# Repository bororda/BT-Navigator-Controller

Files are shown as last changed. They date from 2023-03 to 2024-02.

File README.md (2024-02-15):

# Intro

This is a Bluetooth based smartphone/ tablet controller for the comfortable interactions with your navigation (not limited to but mainly for _OsmAnd_, _Locus Map_ and _Rally Roadbook Reader_ app) while riding your bike.

Current models are designed to be mounted over the grips, i.e. no manipulation with the handlebar setup is required other than just securing the controller on the left hand grip. Eventually the versions with other mounting diameters will appear.

The solution consists of 2 parts connected with the cable: hand grip module and the box with a dev board and batteries.

## Right now there're two versions of the grip module:
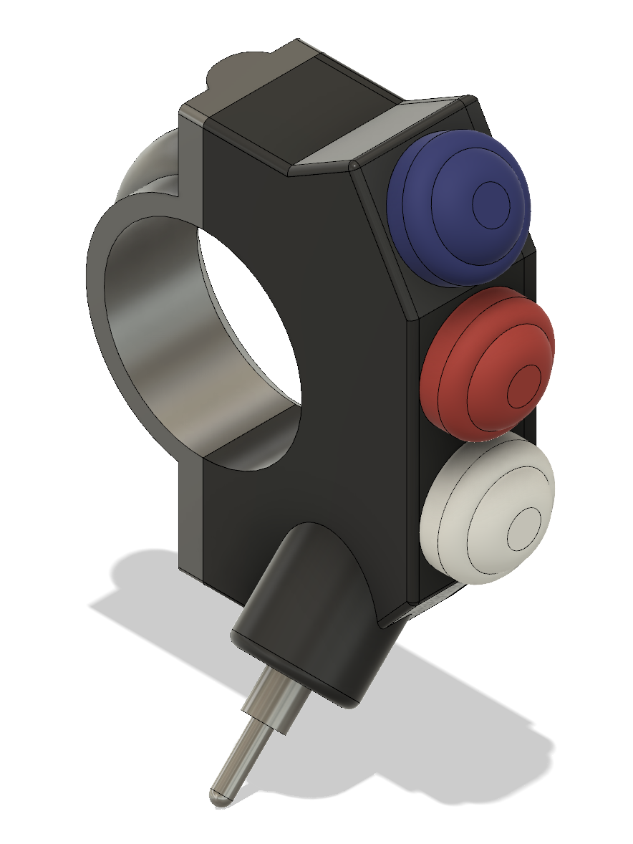
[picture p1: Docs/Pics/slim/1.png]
Slim Slim model
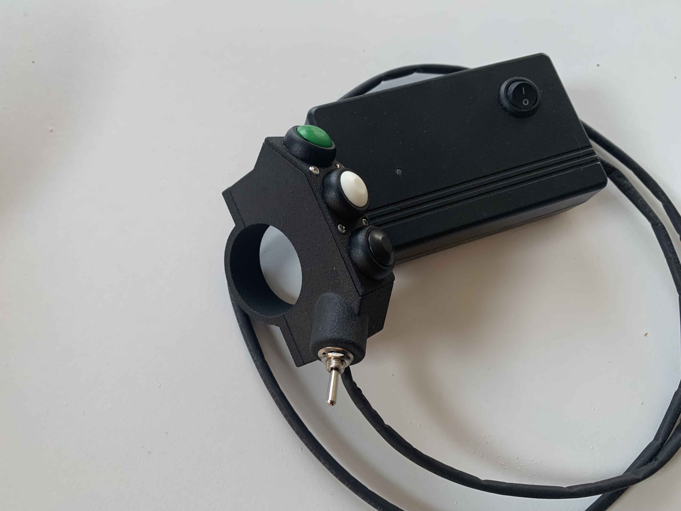
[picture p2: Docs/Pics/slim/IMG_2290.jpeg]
Slim Slim Assembled
1. **V2 aka Slim** redesigned controller. As rigit as V1, but signnificantly slimmer, with ergonomicly designed toggle switch position.   
2. **V1** which is quite wide and eats up a lot of grip space, plus it's looking rather basic - still functioning well. If printed out of nylon is rigit as hell. I personally would definitely go for the V2 Slim, but if you're curious you can still check the V1 here: [V1 3D](Docs/Pics/V1/1.png) and [V1 Assembled](Docs/Pics/V1/IMG_2272.jpeg)

The box with a dev board and batteries is basically somewhat of a water protected box to store the brains of the controller - check the [MAC Parts](Docs/parts.numbers) or [Excel Parts but w/o pics](Docs/parts.xlsx) for details.

# Instructions
## How to assemble one
1. Get the list of components listed in [MAC Parts](Docs/parts.numbers) or [Excel Parts but w/o pics](Docs/parts.xlsx)
2. Order the 3D prints. You gotta chose between the [V1](V1/Hardware/casing) and [V2 Slim](Slim/Hardware/case). Both are perfectly fine and durable, except the V2 is obviously slimmer and more compact compared to V1.
3. Flash the board. Both V1 and V2 Slim are based on ESP32 Wroom. You'll need the [BLE lib](Code/ESP32-BLE-Keyboard-master). Switching to [Seeed Studio XIAO nRF52840](https://wiki.seeedstudio.com/XIAO_BLE/)  is yet to come - this should improve the size of the external box.
4. Assemble the project. You'll need a soldering iron! Should you have any troubles on this step, give me a shout.
5. Turn the device on and connect it to your smartphone from Settings->Bluetooth
6. Configure the apps on the phone to react to the keys properly

## Buttons

### Buttons Defaults
From top to bottom the keys sent to the device are: letter "C", "Up Arrow", "Down Arrow". Toggle switch Vol+ when pressed towards, and Vol- when pulled.

### Navigation
Buttons cover the main functionality for the 2 navigation apps that are the most interesting for the author:
1. C to center the map
2. Vol+ and Vol- to zoom in and out
3. Up and Down Arrows for OsmAnd to move the map up and down

## Rally Roadbook Reader
Work in progress.
The solution is trivial: add a hardware switch and adjust the code to switch the key mapping. Unfortunately there's no common solution for both navigation and rally roadbook as some keys are different, but the common keys do different things. RRR does not let other keys to be assigned in the app, or the author was not clever enough to finnd the hidden settings.

## OsmAnd Setup
Follow the guide from the [official page](https://osmand.net/docs/user/map/interact-with-map/#external-input-device-buttons) to turn on the support of the External Input Devices. Also enable zoom in-out with volume buttons. If for any reason you would not want to do this last step, you would need to reconfigure the .ino sketch and adjust the code to send other keys.

# V1 vs. V2 Slim
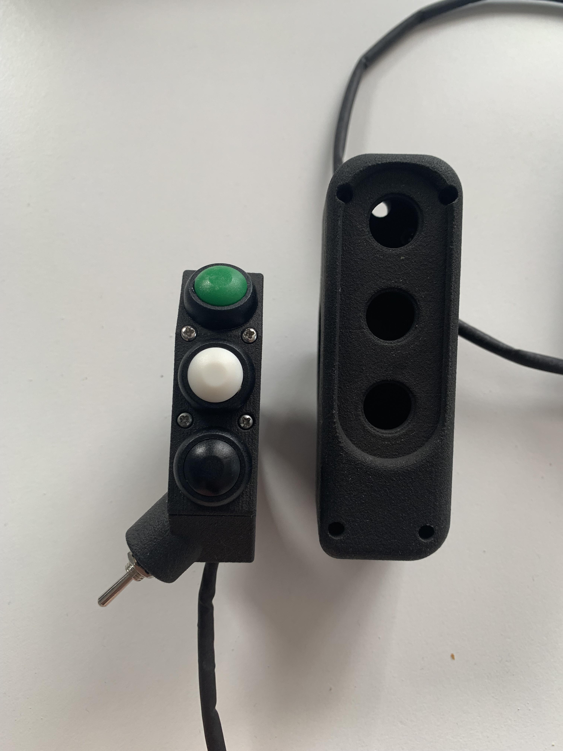
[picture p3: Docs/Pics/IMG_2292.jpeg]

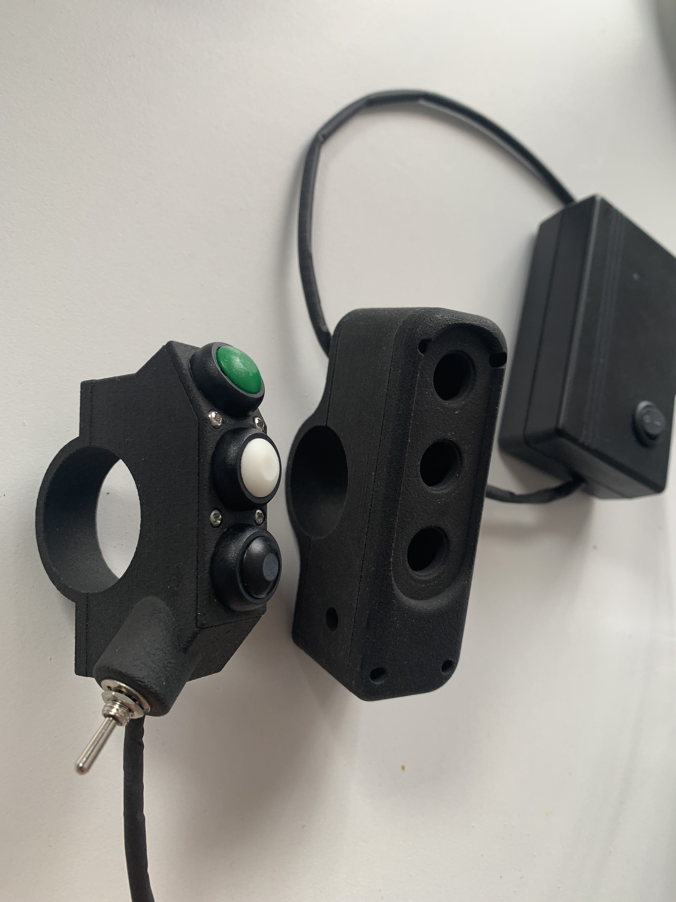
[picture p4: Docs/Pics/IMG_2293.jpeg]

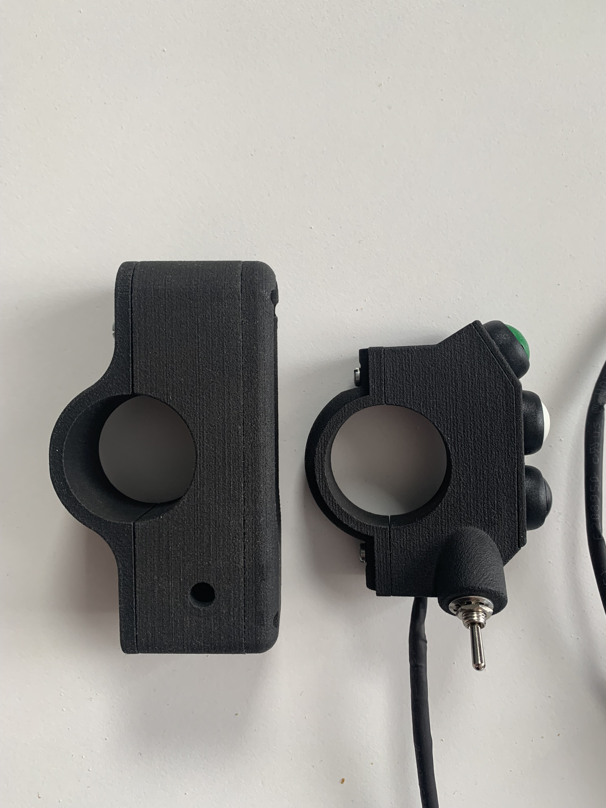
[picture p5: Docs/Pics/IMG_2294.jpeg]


# Credits
This project was inspired by another open source project [rallyrampage](https://www.rallyrampage.com/product/bluetooth-navigation-handlebar-controller-version-1-7-3-6b/)
You cannot reinvent something so simple, but i did put some efforts to make the controller look just a bit nicer and reduce the costs of the components.

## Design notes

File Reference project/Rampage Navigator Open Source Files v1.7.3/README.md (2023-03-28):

WELCOME TO THE RALLY RAMPAGE NAVIGATION CONTROLLER

This project is for developing a bluetooth handlebar controller to use for navigation whilst riding motorbike.

The project was started by Eugene Beetge from Rally Rampage. The original designs and coding are all from Eugene.

For more information please visit: 

https://www.rallyrampage.com

or 

email at info@rallyrampage.com

REVISIONS & RELEASES

Version 1.7.3 Release date 2022/03/31
-added default mode option to startup in an app
-added battery testing and display on mobile using keyboard text when in Mode select and pushing button 5 which is unassigned with an app. Used now for battery voltage testing and display push
-cleaned up code in other areas
-better notes inside code

Version 1.7.2  (Release date 2021/12/17)
- updated code for all 4 new apps
	Locus Maps
	Rally Navigator
	OsMand Maps
	Piste Roadbook

Version 1.7  (Release date 2021/12/14)
- complete new functionality using rocker switches.
- rocker one mode is to select one of 5 apps, with LED flicker to confirm app selected.
- rocker two mode is using the app selected.
- accomodating for normaly-open and normaly-closed controller buttons in code. Easy to select
- code half size, double the speed

Version 1.5  (Release date 2021/09/27)
- included 3d print files
- 2 versions of 3d print files with different designs to make manufacturing easier
- permanent power option in the design

Version 1.2 (Release date 2021/06/27)
- original open source files

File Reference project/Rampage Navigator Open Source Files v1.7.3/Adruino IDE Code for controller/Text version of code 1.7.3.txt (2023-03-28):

//VERSION 1.7.3
// This version allow for the selection of various apps by putting the unit in MODE as well as reading the battery status
// and then selecting the appropriate app based on the button pressed. Here are the apps and buttons
// WHEN YOU PLACE THE UNIT IN MODE SELECT AND THE LED IS RED, BY PRESSING THE FOLLOWING BUTTONS YOU CAN SELECT THE APP THE KEYS ARE ASSIGNED TO FOR WHEN YOU GO BACK TO RIDING MODE
// Button 1. Locus Maps
// Button 2. Rally Navigator
// Button 3. OsmAnd
// Button 4. Piste Roadbook Reader
// Button 5. Battery level check and sending back to Androidn device as text. Can be seen on any text interface
// Toggle 6 (Toggle switch). Locus Maps (as backup incase your buttons to select arent working or you are using something else)
// Toggle 7 (Toggle switch). Rally Navigator  (as backup incase your buttons to select arent working or you are using something else)

#include <Arduino.h>
#include <SPI.h>
#include "Adafruit_BLE.h"
#include "Adafruit_BluefruitLE_SPI.h"
#include "Adafruit_BluefruitLE_UART.h"

#if SOFTWARE_SERIAL_AVAILABLE
#include <SoftwareSerial.h>
#endif

Adafruit_BluefruitLE_SPI ble(8, 7, 4);

//Factory reset to 0 for no reset, or 1 to factory reset when scketch starts
#define FACTORYRESET_ENABLE 0

/////////////////////////////////////////////////////////
//Choose some setting that may be different on your unit
/////////////////////////////////////////////////////////

//APP LED SEQUENCE OF COLOUR. SWOP THE VALUE OF YOUR COLCOURS ARE WRONG WAY AROUND
const int ledGREEN = A1;
const int ledRED = A0;

//PUSH BUTTONS STATE FOR NORMALLY OPEN AND NORMALLY CLOSED
//FOR Normally open buttons keen the state LOW.
//FOR Normally closed buttons change the state to HIGH
const int button1state = LOW;
const int button2state = LOW;
const int button3state = LOW;
const int button4state = LOW;
const int button5state = LOW;
const int button6state = LOW;
const int button7state = LOW;

/////////////////////////////////////////////////////////

//PUSH BUTTONS
const int button1 = 12; //Black
const int button2 = 11; //Dark blue
const int button3 = 10; //Blue
const int button4 = 9; //White
const int button5 = 5; //Dark blue

//TOGGLE SWITCH BUTTONS
const int button6 = A2;
const int button7 = A3;

//APP SWITCH BUTTON
const int modeSelect = 6;
int softApp; //Keep softapp default 0 when starting up
//int softApp = 1; //preset softapp to app 3 when starting up

//BUTTON & TOGGLE FIXED SCROLL SPEED
const int buttonWait = 250;
const int toggleWait = 20;

////////////////////////////////////////////////////////////////////////////////////////////////
void setup()
{

  Serial.begin(115200);
  Serial.println("Starting up ...");

  /////////////////////////////////////////
  ////////SETUP BLUETOOTH
  /////////////////////////////////////////

  //Factory reset if enabled above
  if ( FACTORYRESET_ENABLE )
  {
    /* Perform a factory reset to make sure everything is in a known state */
    Serial.println(F("Performing a factory reset: "));
    if ( ! ble.factoryReset() ){
      //error(F("Couldn't factory reset"));
    }
  }

  //Setup BT
  ble.begin(false);
  ble.sendCommandCheckOK("AT+GAPDEVNAME=Rampage_Controller_1.7.3");
  ble.sendCommandCheckOK("AT+BLEHIDEN=On");
  ble.sendCommandCheckOK("AT+BleKeyboardEn=On");
  Serial.println("Bluetooth Started OK!");
  digitalWrite(LED_BUILTIN, LOW);

  //Double reset to see if it improves auto connect on Androidn devices
  ble.reset();
  delay(2000);
  ble.reset();

  /* Disable command echo from Bluefruit */
  ble.echo(false);

  /* Print Bluefruit information */
  Serial.println("Requesting Bluefruit info:");
  ble.info();

  //Push buttons
  pinMode(button1, INPUT_PULLUP);
  pinMode(button2, INPUT_PULLUP);
  pinMode(button3, INPUT_PULLUP);
  pinMode(button4, INPUT_PULLUP);
  pinMode(button5, INPUT_PULLUP);
  //Toggle switch buttons
  pinMode(button6, INPUT_PULLUP);
  pinMode(button7, INPUT_PULLUP);
  //Mode LEDs
  pinMode(ledGREEN, OUTPUT);
  pinMode(ledRED, OUTPUT);
  //App rocker switch
  pinMode(modeSelect, INPUT_PULLUP);

}

////////////////////////////////////////////////////////////////////////////////////////////////////////////////////////////////////////////////////////////////////////////////////////////////
void loop()
{

  //  Serial.print("SoftApp # at startup is: ");
  //  Serial.println(softApp);

  //////////////////////////////////////////////////////////////
  // START SOFT APP SELECT LOOP
  //////////////////////////////////////////////////////////////
  
  //Start of select softapp 1
  if (digitalRead(modeSelect) == LOW) {
    digitalWrite(ledRED, HIGH);
    digitalWrite(ledGREEN, LOW);
    if (digitalRead(button1) == button1state) {
      softApp = 1;
      Serial.println ("While in Mode Select you have selected softApp 1: Locus Maps.");
      ble.println("AT+BleKeyboard=SoftApp 1: Locus Maps. ");
      digitalWrite(ledRED, LOW);
      delay (500);
      for (int i = 1; i <= softApp; i++) {
        digitalWrite(ledGREEN, HIGH);
        delay(300);
        digitalWrite(ledGREEN, LOW);
        delay(300);
      }
      delay (300);
      digitalWrite(ledRED, HIGH);
    } 
    //End of select softapp 1

    //Start of select softapp 2
    if (digitalRead(button2) == button2state) {
      softApp = 2;
      Serial.println ("While in Mode Select you have selected softApp 2: Rally navigator.");
      ble.println("AT+BleKeyboard=SoftApp 2: Rally navigator. ");
      digitalWrite(ledRED, LOW);
      delay (500);
      for (int i = 1; i <= softApp; i++) {
        digitalWrite(ledGREEN, HIGH);
        delay(300);
        digitalWrite(ledGREEN, LOW);
        delay(300);
      }
      delay (300);
      digitalWrite(ledRED, HIGH);
    } 
    //End of select softapp 2

    //Start of select softapp 3
    if (digitalRead(button3) == button3state) {
      softApp = 3;
      Serial.println ("While in Mode Select you have selected softApp 3: OsMand.");
      ble.println("AT+BleKeyboard=SoftApp 3: OsMand. ");
      digitalWrite(ledRED, LOW);
      delay (500);
      for (int i = 1; i <= softApp; i++) {
        digitalWrite(ledGREEN, HIGH);
        delay(300);
        digitalWrite(ledGREEN, LOW);
        delay(300);
      }
      delay (300);
      digitalWrite(ledRED, HIGH);
    } 
    //End of select softapp 3

    //Start of select softapp 4
    if (digitalRead(button4) == button4state) {
      softApp = 4;
      Serial.println ("While in Mode Select you have selected softApp 4: Piste Roadbook Reader.");
      ble.println("AT+BleKeyboard=SoftApp 4: Piste Roadbook Reader. ");
      digitalWrite(ledRED, LOW);
      delay (500);
      for (int i = 1; i <= softApp; i++) {
        digitalWrite(ledGREEN, HIGH);
        delay(300);
        digitalWrite(ledGREEN, LOW);
        delay(300);
      }
      delay (300);
      digitalWrite(ledRED, HIGH);
    } 
    //End of select softapp 4

    //Start of select softapp 5
    if (digitalRead(button5) == button5state) {
      //softApp = 0;
      Serial.println ("While in Mode Select you have selected Button 5: VBat Voltage Check.");
      //ble.println("AT+BleKeyboard=Button 5: VBat Voltage Check. ");

      ////Read battery for UART sending unique to this button in mode
      #define VBATPIN A9 // Measuring battery first on pin A9
      pinMode(button4, LOW); //Button 4 assigned to A9 for voltage just set to LOW to give correct values
      float measuredvbat = analogRead(VBATPIN);
      measuredvbat *= 2;    // we divided by 2, so multiply back
      measuredvbat *= 3.3;  // Multiply by 3.3V, our reference voltage
      measuredvbat /= 1024; // convert to voltage
      if (measuredvbat <= 4) {
        Serial.print("Battery seems to be connected and voltage is: " );
        Serial.println(measuredvbat);
        //ble.print("AT+BleKeyboard=");
        //ble.println("Battery seems to be connected and charging. ");
        ble.print("AT+BleKeyboard= ");
        ble.print("PIN or battery voltage: ");
        ble.print(measuredvbat);
        ble.println("v. ");
      }
      else {
        Serial.print("Battery does NOT seem to be connected, PIN voltage is: " );
        Serial.println(measuredvbat);
        //ble.print("AT+BleKeyboard=");
        //ble.println("The battery does NOT seem to be connected. ");
        ble.print("AT+BleKeyboard= ");
        ble.print("PIN or battery voltage: ");
        ble.print(measuredvbat);
        ble.println("v. ");
      }
      pinMode(button4, INPUT_PULLUP); //Button 4 assigned to voltage pin 9 pulled up for deafult function again

      digitalWrite(ledRED, LOW);
      delay (500);
      for (int i = 1; i <= softApp; i++) {
        digitalWrite(ledGREEN, HIGH);
        delay(300);
        digitalWrite(ledGREEN, LOW);
        delay(300);
      }
      delay (300);
      digitalWrite(ledRED, HIGH);
    } 
    //End of select softapp 5

    //Start of select softapp 6
    if (digitalRead(button6) == button6state) {
      softApp = 1;
      Serial.println ("While in Mode Select you have selected softApp 1: Locus Maps button mapping.");
      ble.println("AT+BleKeyboard=SoftApp 1: Locus Maps. ");
      digitalWrite(ledRED, LOW);
      delay (500);
      for (int i = 1; i <= softApp; i++) {
        digitalWrite(ledGREEN, HIGH);
        delay(300);
        digitalWrite(ledGREEN, LOW);
        delay(300);
      }
      delay (300);
      digitalWrite(ledRED, HIGH);
    } 
    //End of select softapp 6

    //Start of select softapp 7
    if (digitalRead(button7) == button7state) {
      softApp = 2;
      Serial.println ("While in Mode Select you have selected softApp 2: Rally navigator.");
      ble.println("AT+BleKeyboard=SoftApp 2: Rally Navigator. ");
      digitalWrite(ledRED, LOW);
      delay (500);
      for (int i = 1; i <= softApp; i++) {
        digitalWrite(ledGREEN, HIGH);
        delay(300);
        digitalWrite(ledGREEN, LOW);
        delay(300);
      }
      delay (300);
      digitalWrite(ledRED, HIGH);
    } 
    //End of select softapp 7
    
  }

  //////////////////////////////////////////////////////////////
  // END SOFT APP SELECT LOOP
  //////////////////////////////////////////////////////////////

  //////////////////////////////////////////////////////////////
  // START SOFT APP RUN LOOP
  //////////////////////////////////////////////////////////////
  if (digitalRead(modeSelect) == HIGH) {
    digitalWrite(ledRED, LOW);
    digitalWrite(ledGREEN, HIGH);

    if (softApp == 0) { //App 0 No softApp value yet
      Serial.println("You are in softApp: ZERO");
      digitalWrite(ledGREEN, HIGH);
      delay(300);
      digitalWrite(ledGREEN, LOW);
      delay(300);
    } //End softapp 0

    if (softApp == 1) {  // App 1 Locus Maps
      digitalWrite(ledGREEN, HIGH);
      Serial.println("You are in softApp: Locus");
      //PUSH BUTTONS
      if (digitalRead(button1) == button1state) {
        Serial.println("Button 1");
        ble.sendCommandCheckOK("AT+BleHidControlKey=VOLUME+");
        digitalWrite(ledGREEN, LOW);
        delay(buttonWait);
        digitalWrite(ledGREEN, HIGH);
      }
      if (digitalRead(button2) == button2state) {
        Serial.println("Button 2");
        ble.sendCommandCheckOK("AT+BleHidControlKey=VOLUME-");
        digitalWrite(ledGREEN, LOW);
        delay(buttonWait);
        digitalWrite(ledGREEN, HIGH);
      }
      if (digitalRead(button3) == button3state) {
        Serial.println("Button 3");
        ble.sendCommandCheckOK("AT+BLEKEYBOARDCODE=00-00-15-00-00-00-00");
        ble.sendCommandCheckOK("AT+BLEKEYBOARDCODE=00-00");
        digitalWrite(ledGREEN, LOW);
        delay(buttonWait);
        digitalWrite(ledGREEN, HIGH);
      }
      if (digitalRead(button4) == button4state) {
        Serial.println("Button 4");
        ble.sendCommandCheckOK("AT+BLEKEYBOARDCODE=00-00-06-00-00-00-00");
        ble.sendCommandCheckOK("AT+BLEKEYBOARDCODE=00-00");
        digitalWrite(ledGREEN, LOW);
        delay(buttonWait);
        digitalWrite(ledGREEN, HIGH);
      }
      if (digitalRead(button5) == button5state) {
        Serial.println("Button 5");
        ble.sendCommandCheckOK("AT+BLEKEYBOARDCODE=00-00-07-00-00-00-00");
        ble.sendCommandCheckOK("AT+BLEKEYBOARDCODE=00-00");
        digitalWrite(ledGREEN, LOW);
        delay(buttonWait);
        digitalWrite(ledGREEN, HIGH);
      }
      //TOGGLE SWITCH
      if (digitalRead(button6) == button6state) {
        Serial.println("Button 6");
        ble.sendCommandCheckOK("AT+BleHidControlKey=VOLUME+");
        digitalWrite(ledGREEN, LOW);
        delay(buttonWait);
        digitalWrite(ledGREEN, HIGH);
      }
      if (digitalRead(button7) == button7state) {
        Serial.println("Button 7");
        ble.sendCommandCheckOK("AT+BleHidControlKey=VOLUME-");
        digitalWrite(ledGREEN, LOW);
        delay(buttonWait);
        digitalWrite(ledGREEN, HIGH);
      }
    } //End softapp 1

    if (softApp == 2) { // App 2 Rally Navigator
      digitalWrite(ledGREEN, HIGH);
      digitalWrite(ledRED, LOW);
      Serial.println("You are in softApp: Rally Navigator");
      //PUSH BUTTONS
      if (digitalRead(button1) == button1state) {
        Serial.println("Button 1");
        ble.sendCommandCheckOK("AT+BleHidControlKey=VOLUME+");
        digitalWrite(ledGREEN, LOW);
        delay(buttonWait);
        digitalWrite(ledGREEN, HIGH);
      }
      if (digitalRead(button2) == button2state) {
        Serial.println("Button 2");
        ble.sendCommandCheckOK("AT+BleHidControlKey=VOLUME-");
        digitalWrite(ledGREEN, LOW);
        delay(buttonWait);
        digitalWrite(ledGREEN, HIGH);
      }
      if (digitalRead(button3) == button3state) {
        Serial.println("Button 3");
        ble.sendCommandCheckOK("AT+BLEKEYBOARDCODE=00-00-15-00-00-00-00"); //Map Up or turn r
        ble.sendCommandCheckOK("AT+BLEKEYBOARDCODE=00-00");
        digitalWrite(ledGREEN, LOW);
        delay(buttonWait);
        digitalWrite(ledGREEN, HIGH);
      }
      if (digitalRead(button4) == button4state) {
        Serial.print("Button 4");
        ble.sendCommandCheckOK("AT+BleHidControlKey=MEDIANEXT");
        digitalWrite(ledGREEN, LOW);
        delay(buttonWait);
        digitalWrite(ledGREEN, HIGH);
      }
      if (digitalRead(button5) == button5state) {
        Serial.println("Button 5");
        ble.sendCommandCheckOK("AT+BleHidControlKey=MEDIAPREVIOUS");
        digitalWrite(ledGREEN, LOW);
        delay(buttonWait);
        digitalWrite(ledGREEN, HIGH);
      }
      //TOGGLE SWITCH
      if (digitalRead(button6) == button6state) {
        Serial.println("Button 6");
        ble.sendCommandCheckOK("AT+BleHidControlKey=MEDIANEXT");
        digitalWrite(ledGREEN, LOW);
        delay(buttonWait);
        digitalWrite(ledGREEN, HIGH);
      }
      if (digitalRead(button7) == button7state) {
        Serial.println("Button 7");
        ble.sendCommandCheckOK("AT+BleHidControlKey=MEDIAPREVIOUS");
        digitalWrite(ledGREEN, LOW);
        delay(buttonWait);
        digitalWrite(ledGREEN, HIGH);
      }
    } //End softapp 2

    if (softApp == 3) { // App 3 OsMand
      digitalWrite(ledGREEN, HIGH);
      digitalWrite(ledRED, LOW);
      Serial.println("You are in softApp: OsMand");
      //PUSH BUTTONS
      if (digitalRead(button1) == button1state) {
        Serial.println("Button1");
        ble.sendCommandCheckOK("AT+BLEKEYBOARDCODE=00-00-52-00-00-00-00");
        ble.sendCommandCheckOK("AT+BLEKEYBOARDCODE=00-00");
        digitalWrite(ledGREEN, LOW);
        delay(buttonWait);
        digitalWrite(ledGREEN, HIGH);
      }
      if (digitalRead(button2) == button2state) {
        Serial.println("Button2");
        ble.sendCommandCheckOK("AT+BLEKEYBOARDCODE=00-00-51-00-00-00-00");
        ble.sendCommandCheckOK("AT+BLEKEYBOARDCODE=00-00");
        digitalWrite(ledGREEN, LOW);
        delay(buttonWait);
        digitalWrite(ledGREEN, HIGH);
      }
      if (digitalRead(button3) == button3state) {
        Serial.println("Button3");
        ble.sendCommandCheckOK("AT+BLEKEYBOARDCODE=00-00-06-00-00-00-00");
        ble.sendCommandCheckOK("AT+BLEKEYBOARDCODE=00-00");
        digitalWrite(ledGREEN, LOW);
        delay(buttonWait);
        digitalWrite(ledGREEN, HIGH);
      }
      if (digitalRead(button4) == button4state) {
        Serial.println("Button4");
        ble.sendCommandCheckOK("AT+BLEKEYBOARDCODE=00-00-50-00-00-00-00");
        ble.sendCommandCheckOK("AT+BLEKEYBOARDCODE=00-00");
        digitalWrite(ledGREEN, LOW);
        delay(buttonWait);
        digitalWrite(ledGREEN, HIGH);
      }
      if (digitalRead(button5) == button5state) {
        Serial.println("Button5");
        ble.sendCommandCheckOK("AT+BLEKEYBOARDCODE=00-00-4F-00-00-00-00");
        ble.sendCommandCheckOK("AT+BLEKEYBOARDCODE=00-00");
        digitalWrite(ledGREEN, LOW);
        delay(buttonWait);
        digitalWrite(ledGREEN, HIGH);
      }
      //TOGGLE SWITCHES
      if (digitalRead(button6) == button6state) {
        Serial.println("Button6");
        ble.sendCommandCheckOK("AT+BLEKEYBOARDCODE=00-00-2E-00-00-00-00");
        ble.sendCommandCheckOK("AT+BLEKEYBOARDCODE=00-00");
        digitalWrite(ledGREEN, LOW);
        delay(buttonWait);
        digitalWrite(ledGREEN, HIGH);
      }
      if (digitalRead(button7) == button7state) {
        Serial.println("Button7");
        ble.sendCommandCheckOK("AT+BLEKEYBOARDCODE=00-00-2D-00-00-00-00");
        ble.sendCommandCheckOK("AT+BLEKEYBOARDCODE=00-00");
        digitalWrite(ledGREEN, LOW);
        delay(buttonWait);
        digitalWrite(ledGREEN, HIGH);
      }
    } //End softapp 3

    if (softApp == 4) { // App 4 Piste
      digitalWrite(ledGREEN, HIGH);
      digitalWrite(ledRED, LOW);
      Serial.println("You are in softApp: Piste");
      //PUSH BUTTONS
      if (digitalRead(button1) == button1state) {
        Serial.println("Button 1");
        ble.sendCommandCheckOK("AT+BLEKEYBOARDCODE=00-00-1A-00-00-00-00"); //0x1A Keyboard w and W
        ble.sendCommandCheckOK("AT+BLEKEYBOARDCODE=00-00");
        digitalWrite(ledGREEN, LOW);
        delay(buttonWait);
        digitalWrite(ledGREEN, HIGH);
      }
      if (digitalRead(button2) == button2state) {
        Serial.println("Button 2");
        ble.sendCommandCheckOK("AT+BLEKEYBOARDCODE=00-00-1B-00-00-00-00"); //0x1B Keyboard x and X
        ble.sendCommandCheckOK("AT+BLEKEYBOARDCODE=00-00");
        digitalWrite(ledGREEN, LOW);
        delay(buttonWait);
        digitalWrite(ledGREEN, HIGH);
      }
      if (digitalRead(button3) == button3state) {
        Serial.println("Button 3");
        ble.sendCommandCheckOK("AT+BLEKEYBOARDCODE=00-00-04-00-00-00-00"); //0x04 Keyboard a and A
        ble.sendCommandCheckOK("AT+BLEKEYBOARDCODE=00-00");
        digitalWrite(ledGREEN, LOW);
        delay(buttonWait);
        digitalWrite(ledGREEN, HIGH);
      }
      if (digitalRead(button4) == button4state) {
        Serial.println("Button 4");
        ble.sendCommandCheckOK("AT+BLEKEYBOARDCODE=00-00-07-00-00-00-00"); //0x07 Keyboard d and D
        ble.sendCommandCheckOK("AT+BLEKEYBOARDCODE=00-00");
        digitalWrite(ledGREEN, LOW);
        delay(buttonWait);
        digitalWrite(ledGREEN, HIGH);
      }
      if (digitalRead(button5) == button5state) {
        Serial.println("Button 5");
        ble.sendCommandCheckOK("AT+BLEKEYBOARDCODE=00-00-14-00-00-00-00"); //0x14 Keyboard q and Q
        ble.sendCommandCheckOK("AT+BLEKEYBOARDCODE=00-00");
        digitalWrite(ledGREEN, LOW);
        delay(buttonWait);
        digitalWrite(ledGREEN, HIGH);
      }
      //TOGGLE SWITCH
      if (digitalRead(button6) == button6state) {
        Serial.println("Button 6");
        ble.sendCommandCheckOK("AT+BLEKEYBOARDCODE=00-00-14-00-00-00-00"); //0x07 Keyboard d and D
        ble.sendCommandCheckOK("AT+BLEKEYBOARDCODE=00-00");
        digitalWrite(ledGREEN, LOW);
        delay(buttonWait);
        digitalWrite(ledGREEN, HIGH);
      }
      if (digitalRead(button7) == button7state) {
        Serial.println("Button 7");
        ble.sendCommandCheckOK("AT+BLEKEYBOARDCODE=00-00-7-00-00-00-00"); //0x14 Keyboard q and Q
        ble.sendCommandCheckOK("AT+BLEKEYBOARDCODE=00-00");
        digitalWrite(ledGREEN, LOW);
        delay(buttonWait);
        digitalWrite(ledGREEN, HIGH);
      }
    } //End softapp 4

  } //End of HIGH state button loo

} //End of code

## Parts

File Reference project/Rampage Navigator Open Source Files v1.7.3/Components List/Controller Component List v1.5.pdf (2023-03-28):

# What do you need to build this unit?

You will need to do and get the following:
- some electronic components to build your bluetooth board with buttons.
- A 3D printer to print the controller and housing.
- Soldering and electronic assembly with wires.
- Upload code onto your board using the Arduino IDE.
- Common sense…lol.. No seriously, you will need to think practically.

# Components List

For this project you will need the following components:

© Rally Rampage 2021 - www.rallyrampage.com | Page 3 of 15
Made available under GNU Affero General Public License v3.0
# | Component | Qty | Online link of product and example

1 | Adafruit 32u4 Bluefruit Board | 1 | https://www.robotics.org.za/AF2829
2 | Mini Switch 12mm Waterproof | 6 | https://www.robotics.org.za/PBS-33B
3 | Rocker Switch | 2 | https://www.robotics.org.za/KCD11
4 | Toggle switch - center return | 1 | https://www.communica.co.za/products/m2019ss1w 01 (https://www.communica.co.za/products/m2019ss1w01)
5 | UTP Cable | 1 | Any 8 core UTP cable to use between your switches and your bluetooth box
6 | Wires | 1 | Additional wire to connect between switches and common joints
7 | 2 Colour LED | 1 | https://www.robotics.org.za/RG5-10
8 | M2 Screws | 10 | Miniature screws to attached lids
9 | 1000mA battery (FOR OPTION 1 DESIGN) | 1 | https://www.robotics.org.za/DTP603450?search=100 0ma (https://www.robotics.org.za/DTP603450?search=1000ma) Battery to use for power if not permanently powered
10 | 5v Step down regulator (For OPTION 2 design) | 1 | https://www.robotics.org.za/3792 Used for permanent power on your unit to use your vehicle's 12v perm source.
11 | Micro USB Charging Cable (For OPTION 2 design) | 1 | To be used for the regulator and cut up for perm power OPTION 2

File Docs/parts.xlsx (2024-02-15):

Slim
Part | id | Link | Qty | Ref Pic | Price
Toggle | MTS-123(ON)-OFF-(ON) | https://pl.aliexpress.com/item/1005001709262331.html?curPageLogUid=GSNrjsSGEd9Y&utparam-url=scene:search|query_from: | 1 |  | PLN 13
Push button |  | https://pl.aliexpress.com/item/1005004066257419.html | 3 |  | PLN 10
Main board w/ BLE one to choose | Seeed Xiao BLE nRF52840 | https://botland.com.pl/plytki-zgodne-z-arduino-pozostale/21259-seeed-xiao-ble-nrf52840-arduino-micropython-bluetooth-50-z-wbudowana-antena-seeedstudio-1020104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 | 1 |  | PLN 80
 | ESP-WROOM-32 ESP-32 WiFi Bluetooth MicroUSB | https://botland.com.pl/moduly-wifi-i-bt-esp32/8893-esp32-wifi-bt-42-platforma-z-modulem-esp-wroom-32-zgodny-z-esp32-devkit-5904422337438.html | 1 |  | PLN 65
Rocker switch | Power switch to turn off the power from the board | https://pl.aliexpress.com/item/1005005944839290.html?curPageLogUid=hMoaKqBciwiI&utparam-url=scene:search|query_from: | 1 |  | PLN 10
Battery | Vape battery | Żabka | 1 |  | PLN 20
Casing 3D print | JLC PCB | Use Nylon for durability |  |  | EUR 20
Cable | Any USB cable will work |  | <1m
Case for board & battery |  | https://pl.aliexpress.com/item/1005005467281776.html?curPageLogUid=wZyLFUqxeSAb&utparam-url=scene:search|query_from: | 1 |  | PLN 10
BMS | FDC-2S-2 | Depending on the powering setup you might need to consider a balancer for the double battery setup and a step-down DCDC converter | 1
Total |  |  |  |  | PLN 250

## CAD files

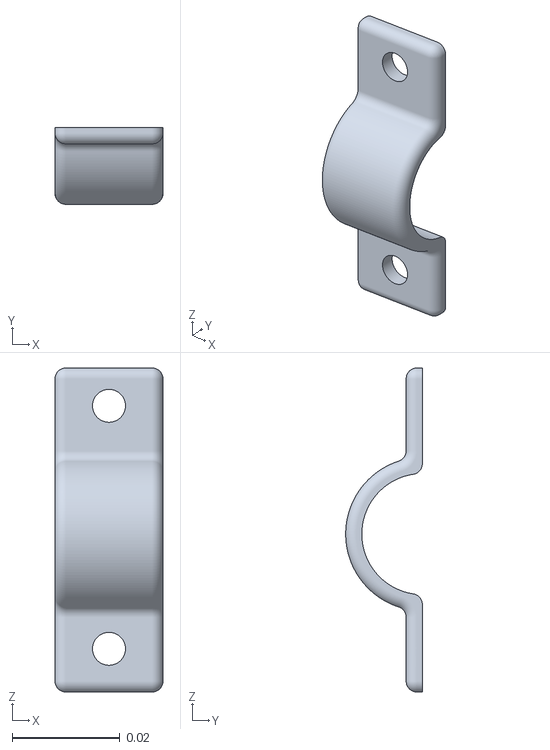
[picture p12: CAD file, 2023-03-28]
Reference project/Rampage Navigator Open Source Files v1.7.3/3D Print files/Bluetooth Controller v1.3 ORIGINAL SOLID DESIGN/STL Files/Controller buttons 1.2.1 Solid one side - Back plate.stl
0.02 x 0.0142 x 0.06

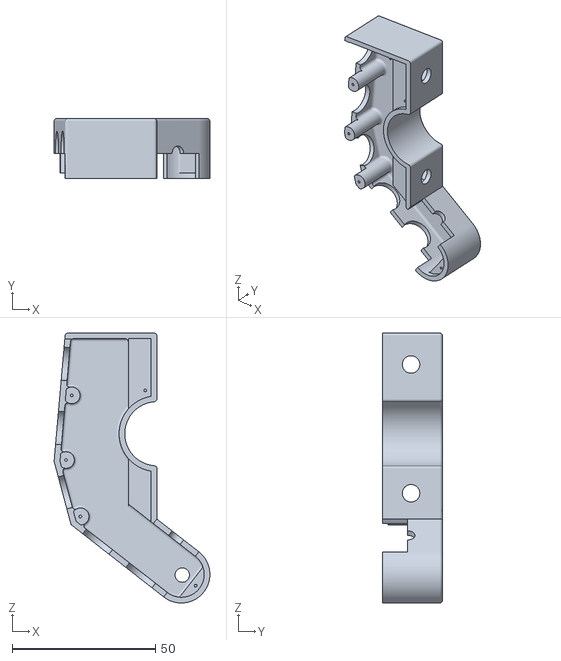
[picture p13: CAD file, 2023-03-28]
Reference project/Rampage Navigator Open Source Files v1.7.3/3D Print files/Bluetooth Controller v1.5 TWO SIDED OPTION FOR EASIER SOLDERING/STL Files/Controller button 1.5 - Body.stl
54.5 x 21.0 x 94.3

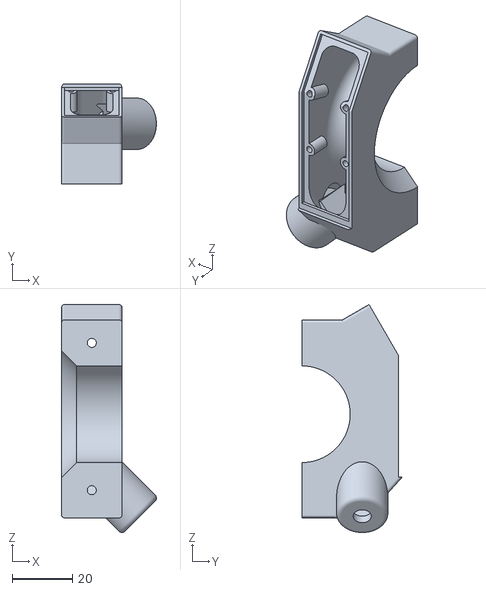
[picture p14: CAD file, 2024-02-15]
Slim/Hardware/case/Body1.stl
31.4 x 33.2 x 75.5

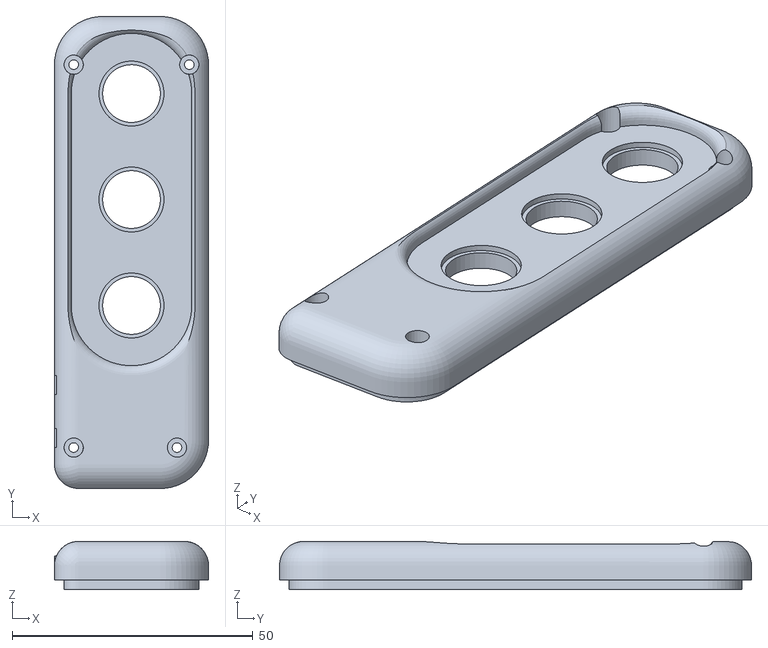
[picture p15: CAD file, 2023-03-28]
V1/Hardware/casing/Untitled3 v1.stl
32.0 x 98.0 x 10.0

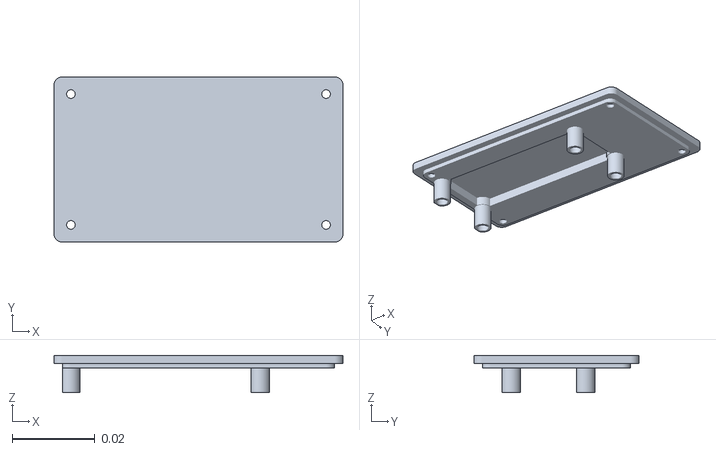
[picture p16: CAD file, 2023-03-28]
Reference project/Rampage Navigator Open Source Files v1.7.3/3D Print files/Bluetooth Controller v1.3 ORIGINAL SOLID DESIGN/STL Files/Bluetooth box 1.1 - Lid.stl
0.07 x 0.04 x 0.009

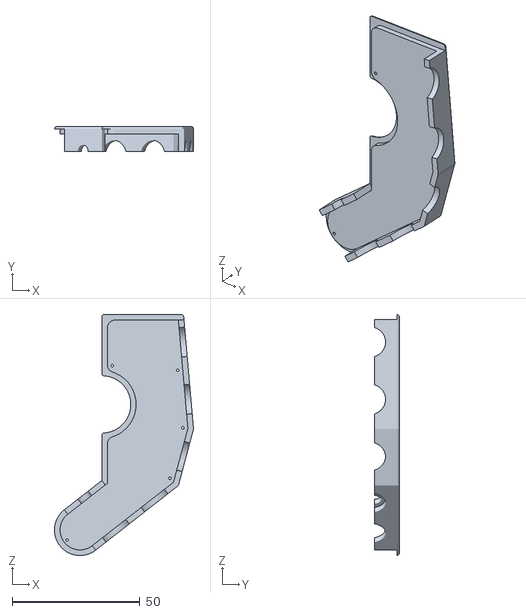
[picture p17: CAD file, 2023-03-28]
Reference project/Rampage Navigator Open Source Files v1.7.3/3D Print files/Bluetooth Controller v1.5 TWO SIDED OPTION FOR EASIER SOLDERING/STL Files/Controller button 1.5 - Lid.stl
54.5 x 9.78 x 94.3

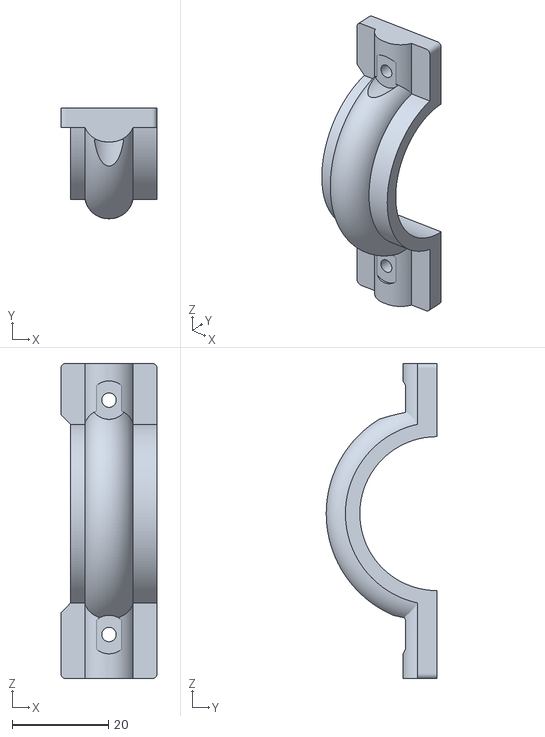
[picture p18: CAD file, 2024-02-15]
Slim/Hardware/case/Body11.stl
20.0 x 23.0 x 65.5

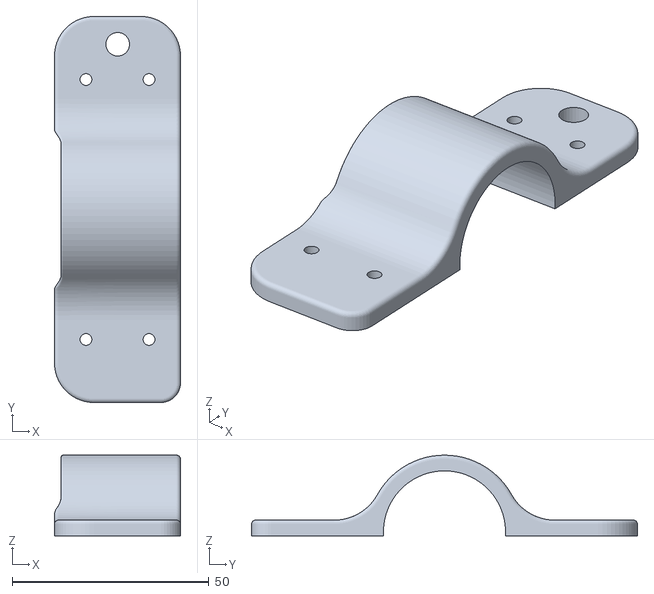
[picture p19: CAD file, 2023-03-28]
V1/Hardware/casing/Untitled2 v1.stl
32.0 x 98.0 x 20.5

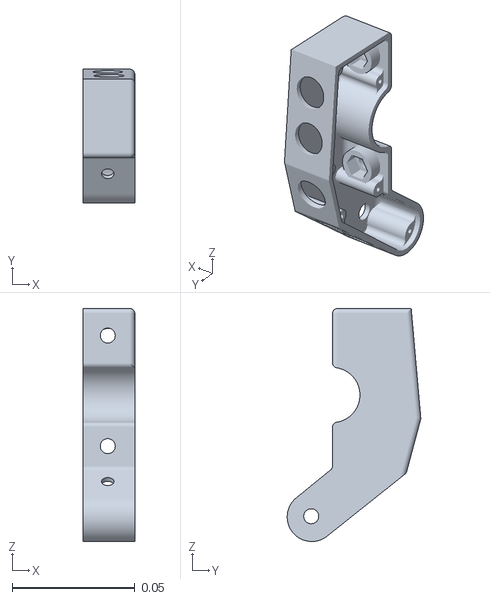
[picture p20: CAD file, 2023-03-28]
Reference project/Rampage Navigator Open Source Files v1.7.3/3D Print files/Bluetooth Controller v1.3 ORIGINAL SOLID DESIGN/STL Files/Controller buttons 1.2.1 Solid one side - Casing.stl
0.021 x 0.0544 x 0.0948

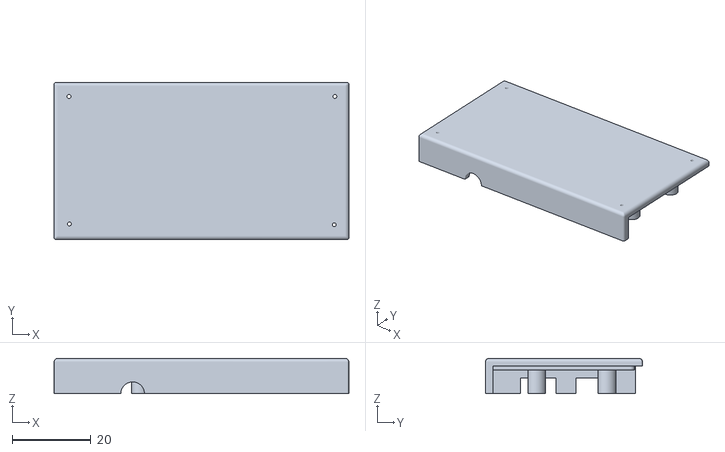
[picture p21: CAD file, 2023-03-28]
Reference project/Rampage Navigator Open Source Files v1.7.3/3D Print files/Bluetooth Controller v1.5 TWO SIDED OPTION FOR EASIER SOLDERING/STL Files/Bluetooth box 1.5 - Lid.stl
75.0 x 40.0 x 9.00

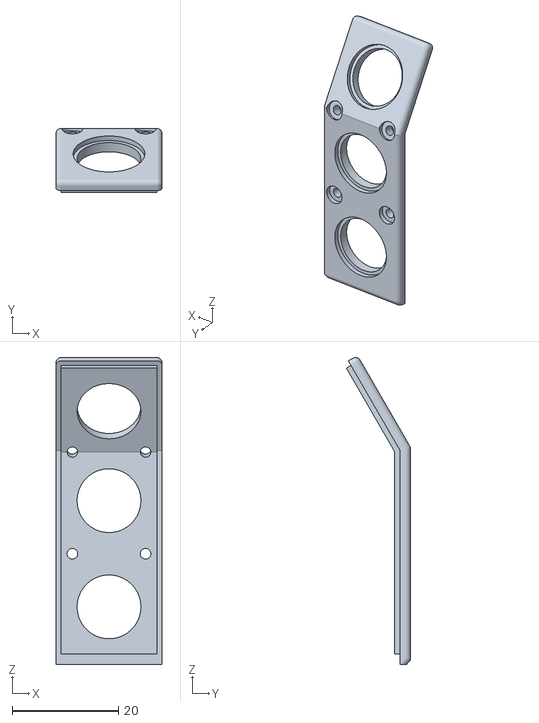
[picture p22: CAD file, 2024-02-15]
Slim/Hardware/case/Body7.stl
20.0 x 12.1 x 57.8

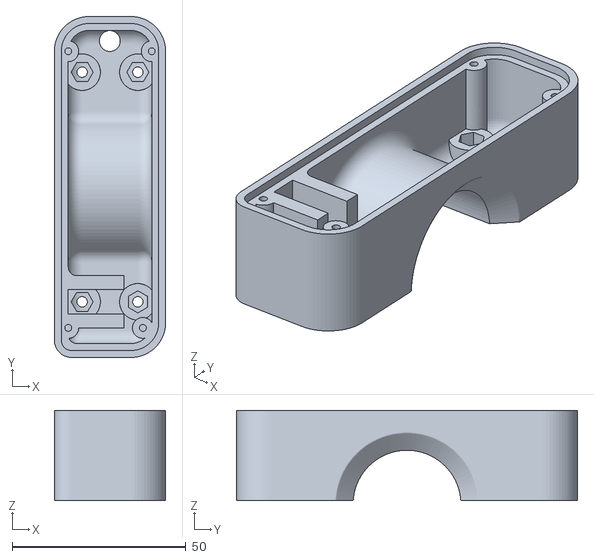
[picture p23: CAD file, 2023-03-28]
V1/Hardware/casing/Untitled v7.stl
32.0 x 98.0 x 26.0

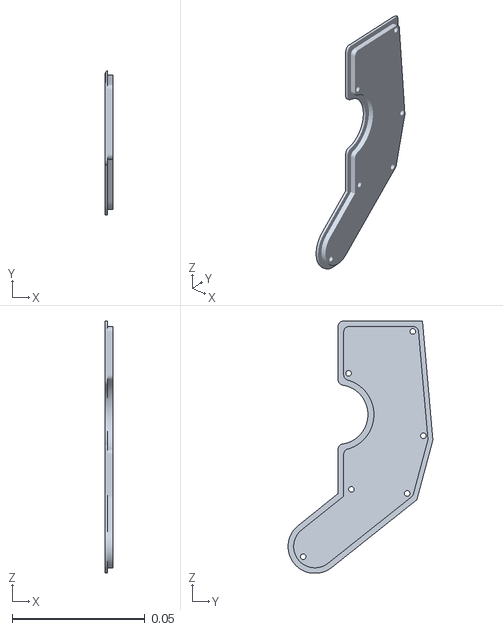
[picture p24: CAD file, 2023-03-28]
Reference project/Rampage Navigator Open Source Files v1.7.3/3D Print files/Bluetooth Controller v1.3 ORIGINAL SOLID DESIGN/STL Files/Controller buttons 1.2.1 Solid one side - lid.stl
0.003 x 0.0545 x 0.0948

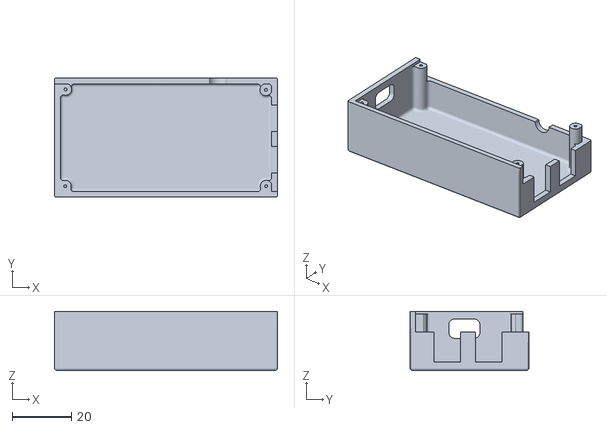
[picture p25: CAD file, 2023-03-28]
Reference project/Rampage Navigator Open Source Files v1.7.3/3D Print files/Bluetooth Controller v1.5 TWO SIDED OPTION FOR EASIER SOLDERING/STL Files/Bluetooth box 1.5 - Box.stl
75.0 x 40.0 x 20.0

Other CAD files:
Reference project/Rampage Navigator Open Source Files v1.7.3/3D Print files/Bluetooth Controller v1.3 ORIGINAL SOLID DESIGN/STL Files/Bluetooth box 1.1 - Box.stl
Reference project/Rampage Navigator Open Source Files v1.7.3/3D Print files/Bluetooth Controller v1.5 TWO SIDED OPTION FOR EASIER SOLDERING/STL Files/Controller button 1.5 - Back.stl
V1/Hardware/casing/Untitled v8.f3d
V1/Hardware/casing/Untitled2 v1.f3d
V1/Hardware/casing/Untitled3 v1.f3d

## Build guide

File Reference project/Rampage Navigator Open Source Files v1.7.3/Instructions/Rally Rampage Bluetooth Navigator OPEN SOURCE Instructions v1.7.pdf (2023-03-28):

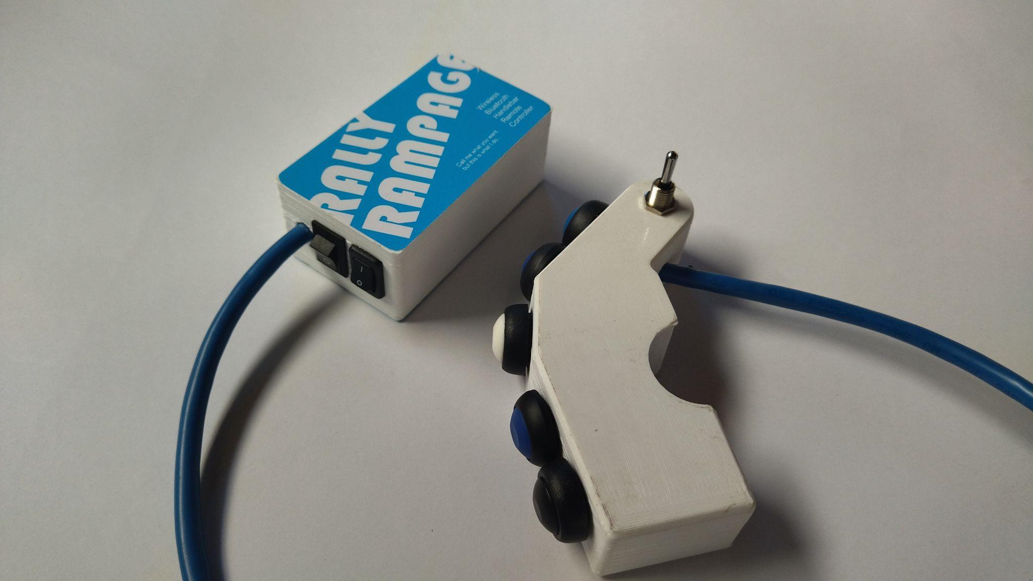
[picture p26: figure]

# Welcome to our

# Rampage Navigator

# Project!

Version 1.7
Updated: 20211214

This document is the explanation and instructions to assemble your own device. In the design and making of the unit, we have kept in mind the use of over-the-counter products. This will play a role in helping you source any exact components or similar components for your project.

What's included in these instructions:
- Components list
- 3D print model files
- Stickers for your little unit
- Some instructions on assembly
- Arduino IDE code for your Adafruit 32u4 board

# So let's get started!

© Rally Rampage 2021 - www.rallyrampage.com | Page 1 of 18
Made available under GNU Affero General Public License v3.0

So let's get started! | 1
What do you need to build this unit? | 3
Components List | 3
Tools | 4
Adafruit Board Default Layout | 5
The Rampage Nav Circuit Design | 6
Notes on circuit assembly | 7
Instructions | 8
Arduino IDE Sketch Explanation | 10
Final testing | 11
Suggestions | 11
Final thoughts | 12
Open Source License - Conditions | 13
GITHUB | 13
© Rally Rampage 2021 - www.rallyrampage.com | Page 2 of 18

## What do you need to build this unit?

You will need to do and get the following:
- some electronic components to build your bluetooth board with buttons.
- A 3D printer to print the controller and housing.
- Soldering and electronic assembly with wires.
- Upload code onto your board using the Arduino IDE.
- Common sense…lol.. No seriously, you will need to think practically.

## Components List

For this project you will need the following components:

# | Component | Qty | Online link of product and example

1 | Adafruit 32u4 Bluefruit Board | 1 | https://www.robotics.org.za/AF2829
2 | Mini Switch 12mm Waterproof | 6 | https://www.robotics.org.za/PBS-33B
3 | Rocker Switch | 2 | https://www.robotics.org.za/KCD11
4 | Toggle switch - center return | 1 | https://www.communica.co.za/products/m2019ss1w0 1 (https://www.communica.co.za/products/m2019ss1w01)
5 | UTP Cable | 1 | Any 8 core UTP cable to use between your switches and your bluetooth box
6 | Wires | 1 | Additional wire to connect between switches and common joints
7 | 2 Colour LED | 1 | https://www.robotics.org.za/RG5-10
8 | M2 Screws | 10 | Miniature screws to attached lids
9 | 1000mA battery (FOR OPTION 1 DESIGN) | 1 | https://www.robotics.org.za/DTP603450?search=100 0ma (https://www.robotics.org.za/DTP603450?search=1000ma) Battery to use for power if not permanently powered
10 | 5v Step down regulator (For OPTION 2 design) | 1 | https://www.robotics.org.za/3792 Used for permanent power on your unit to use your vehicle's 12v perm source.
11 | Micro USB Charging Cable (For OPTION 2 design) | 1 | To be used for the regulator and cut up for perm power OPTION 2
© Rally Rampage 2021 - www.rallyrampage.com | Page 3 of 18

## Tools

You will need the following minimum tools to build this device:
- Soldering iron and solder
- Wire cutters
- Wire stripper
- Computer with Arduino IDE installed
© Rally Rampage 2021 - www.rallyrampage.com | Page 4 of 18

## Adafruit Board Default Layout

The default PIN layout for this Adafruit board is as follows:

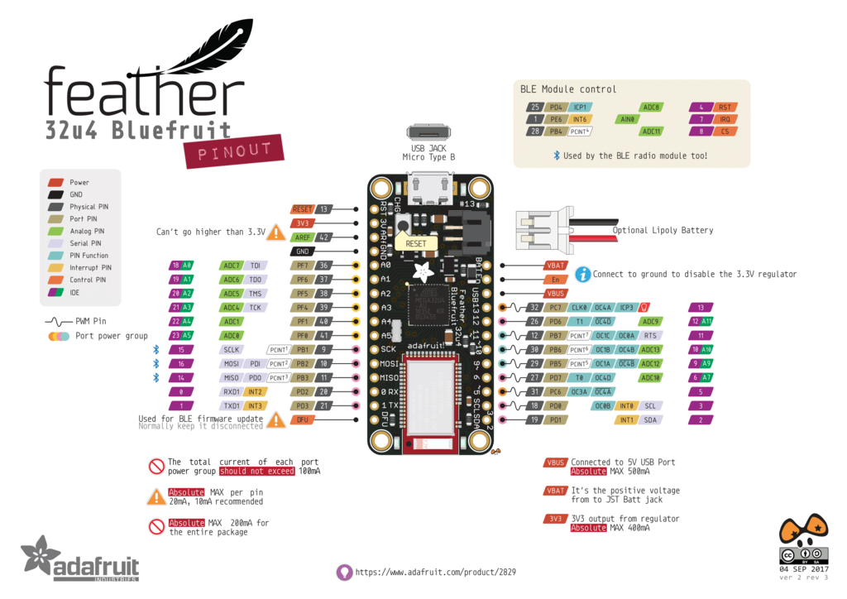
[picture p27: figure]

For more information about this board and how to set it up click this link: https://learn.adafruit.com/adafruit-feather-32u4-bluefruit-le?view=all

© Rally Rampage 2021 - www.rallyrampage.com | Page 5 of 18

## DESIGNS OPTION1: The Rampage Nav Circuit Design with Li Battery

The circuit design and buttons we are using are the following:

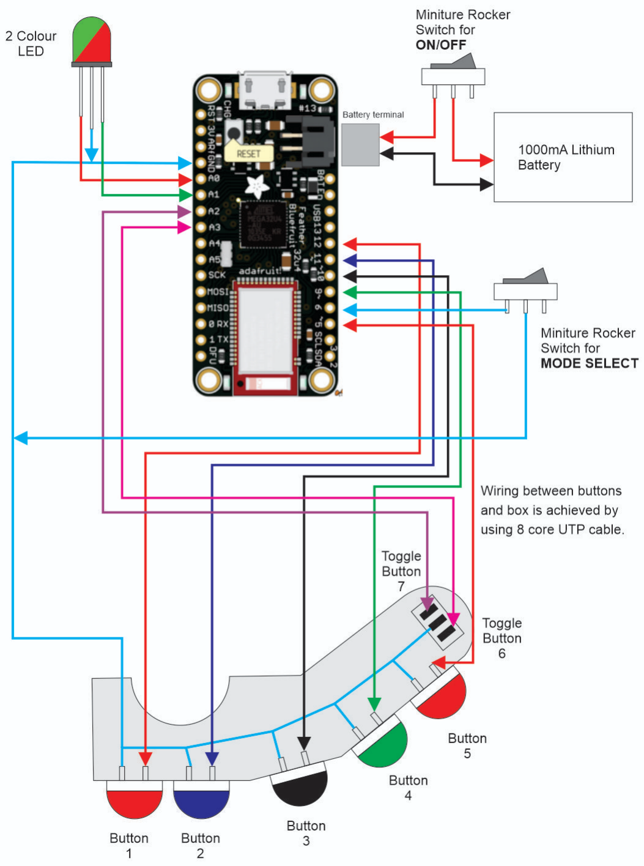
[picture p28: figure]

© Rally Rampage 2021 - www.rallyrampage.com | Page 6 of 18

### Notes on circuit assembly for Option 1

- The ground (GND) will need to go to all the buttons, one rocker switch and the central LED PIN.
- The LED PINs are close enough to just bend and solder directly into the board.
- The main mode LED must stick through the larger hole in the box.
- The battery lies at the bottom of the bluetooth box.
- Wiring between buttons and box is achieved by using 8 core UTP cable.
© Rally Rampage 2021 - www.rallyrampage.com | Page 7 of 18

## DESIGNS OPTION 2: The Rampage Nav Circuit Design with permanent power from 12v vehicle

The circuit design and buttons we are using are the following:

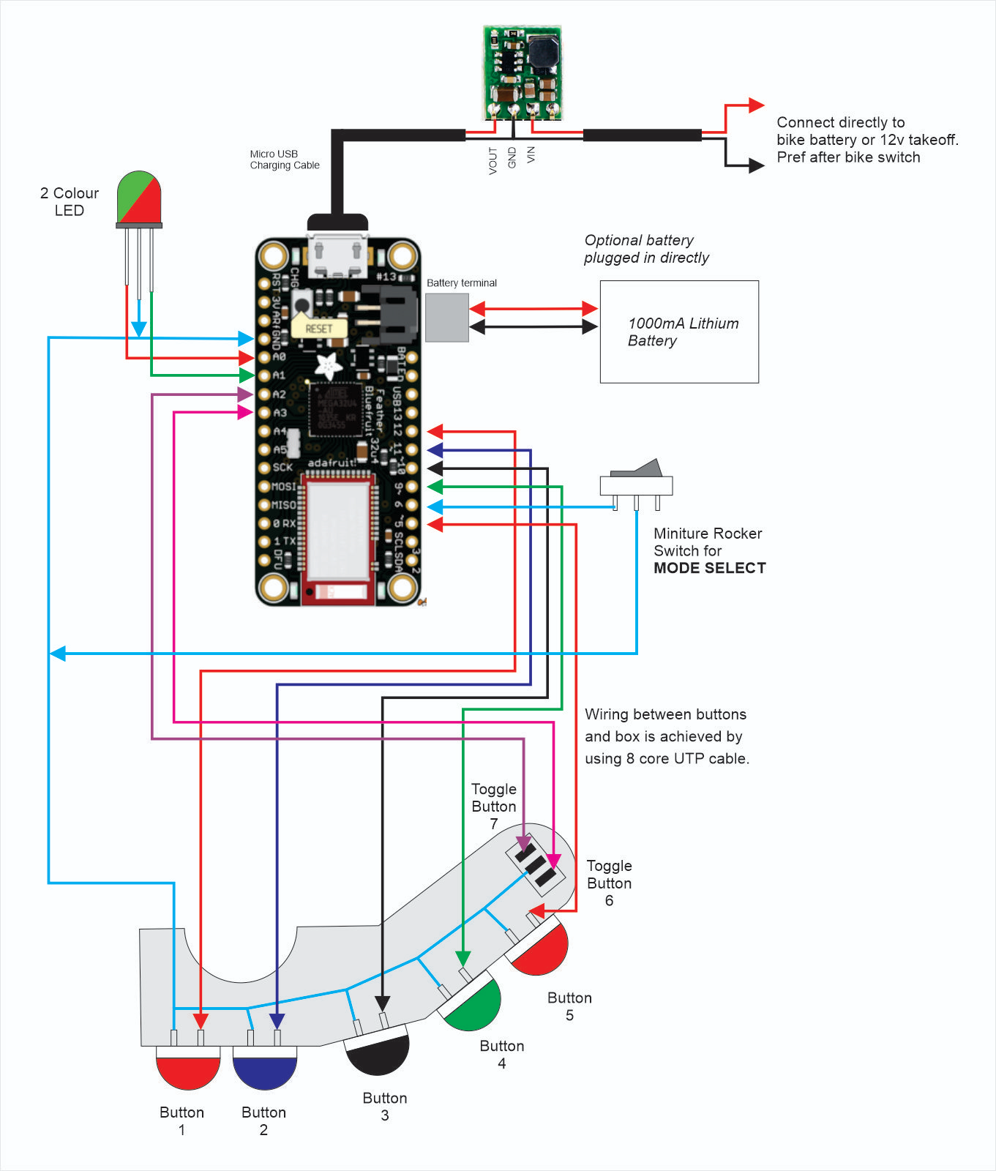
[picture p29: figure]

© Rally Rampage 2021 - www.rallyrampage.com | Page 8 of 18

### Notes on circuit assembly for Option 2:

- The ground (GND) will need to go to all the buttons, one rocker switch and the central LED PIN.
- The LED PINs are close enough to just bend and solder directly into the board.
- The main mode LED must stick through the larger hole in the box.
- The battery lies at the bottom of the bluetooth box.
- Wiring between buttons and box is achieved by using 8 core UTP cable.
- For the perm power use an existing USB charging cable and simply solder the 5v regulator in the middle of the cable. Use the micro USB in your unit and cut off the larger USB as you will need positive and negative directly.
© Rally Rampage 2021 - www.rallyrampage.com | Page 9 of 18

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
v3.0

## DESIGNS OPTION 3: The Rampage Nav Circuit Design with permanent power from 12v vehicle & battery backup

The circuit design and buttons we are using are the following:

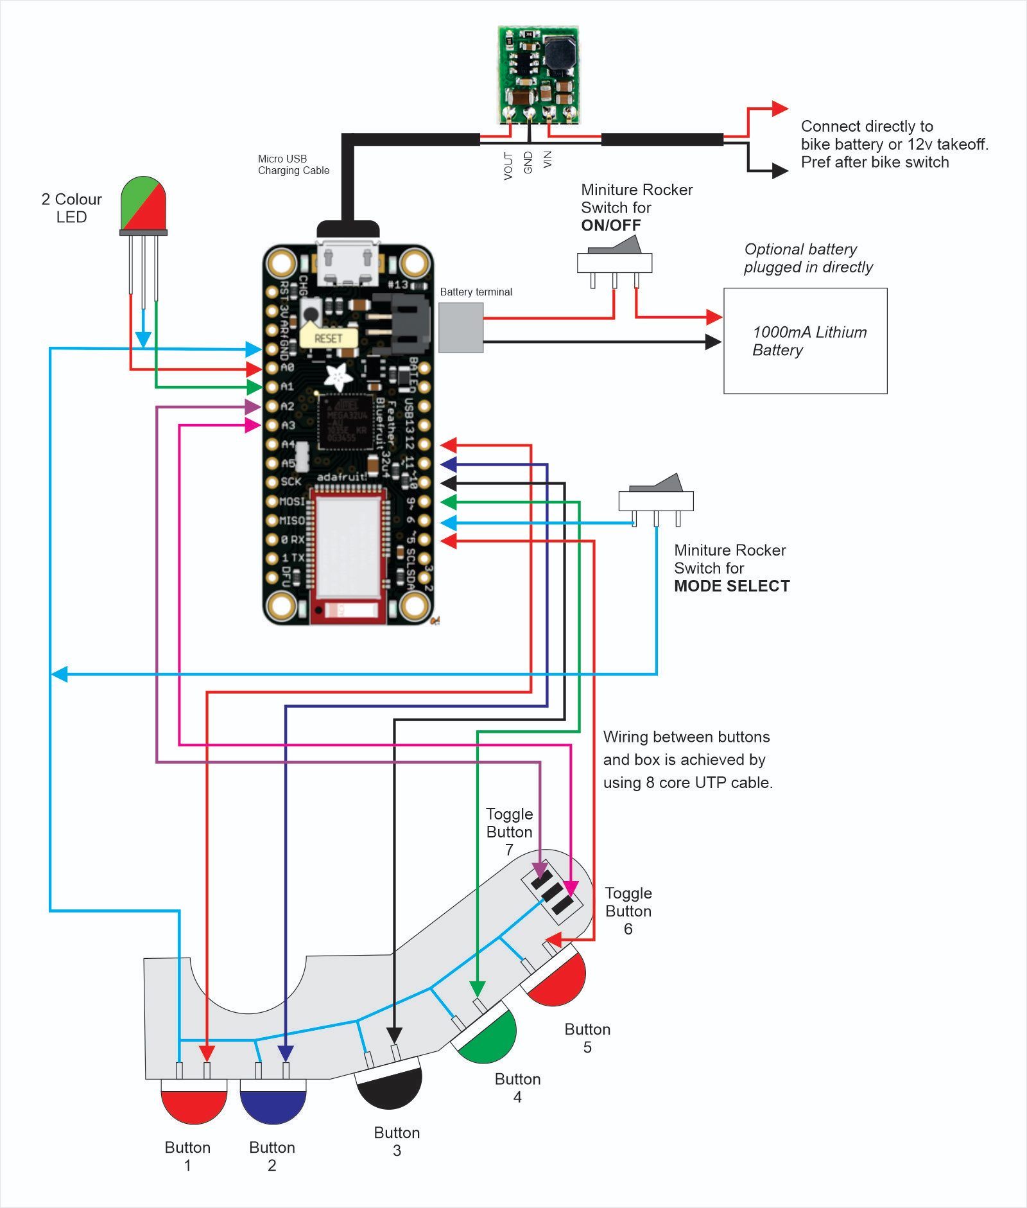
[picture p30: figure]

© Rally Rampage 2021 - www.rallyrampage.com | Page 11 of 18

### Notes on circuit assembly for Option 3:

- The ground (GND) will need to go to all the buttons, one rocker switch and the central LED PIN.
- The LED PINs are close enough to just bend and solder directly into the board.
- The main mode LED must stick through the larger hole in the box.
- The battery lies at the bottom of the bluetooth box.
- Wiring between buttons and box is achieved by using 8 core UTP cable.
- For the perm power use an existing USB charging cable and simply solder the 5v regulator in the middle of the cable. Use the micro USB in your unit and cut off the larger USB as you will need positive and negative directly.
- The rocker switch on the battery will put the battery in the circuit so the board can either run off the battery. Or if permanent power is is on and the battery is turned on, it will automatically charge and act as backup if main power goes off.
© Rally Rampage 2021 - www.rallyrampage.com | Page 12 of 18

## Instructions

Please remember this is a DIY project. You will need to have some understanding of electronics, soldering, assembly and Arduino IDE coding.

As far as I could I have made note of anything that would help you in building your buttons.

### 1. Preparation

a. Buy all components.
b. Prepare soldering and electronics tools for assembly.
c. Install and set up Arduino IDE on your computer to flash the Adafruit board with the code.
d. Cut the UTP cable in approx 30cm length. The one side will go into the button controller and the other will go into the bluetooth housing.

### 2. Boxes

a. Print the 3D files to create your button controller and the bluetooth housing box.
b. You must end up with the button controller housing as well as the bluetooth board housing.

### 3. Buttons

a. Install the 5 push buttons into the 3D printed housing.
b. Insert the toggle switch into the button housing.
c. Insert the rocker switches into the bluetooth housing.

### 4. Soldering

a. Solder the UTP cable between the button controller and the bluetooth. housing. Making sure you solder the correct colour code of the UTP cable wire to the buttons and the pin on the Adafruit board as indicated in the above drawing of the board and its PINs.

### 5. Coding your board

a. Setup your Arduino IDE interface as per these instruction from Adafruit themselves
https://learn.adafruit.com/adafruit-feather-32u4-bluefruit-le/setup
b. Once setup, you can open the Rampage Navigator sketch on your computer
c. I would suggest just Compiling the script to make it all fine.
© Rally Rampage 2021 - www.rallyrampage.com | Page 13 of 18

d. You can upload the script to your board.
e. Start testing buttons using your serial monitor from the IDE

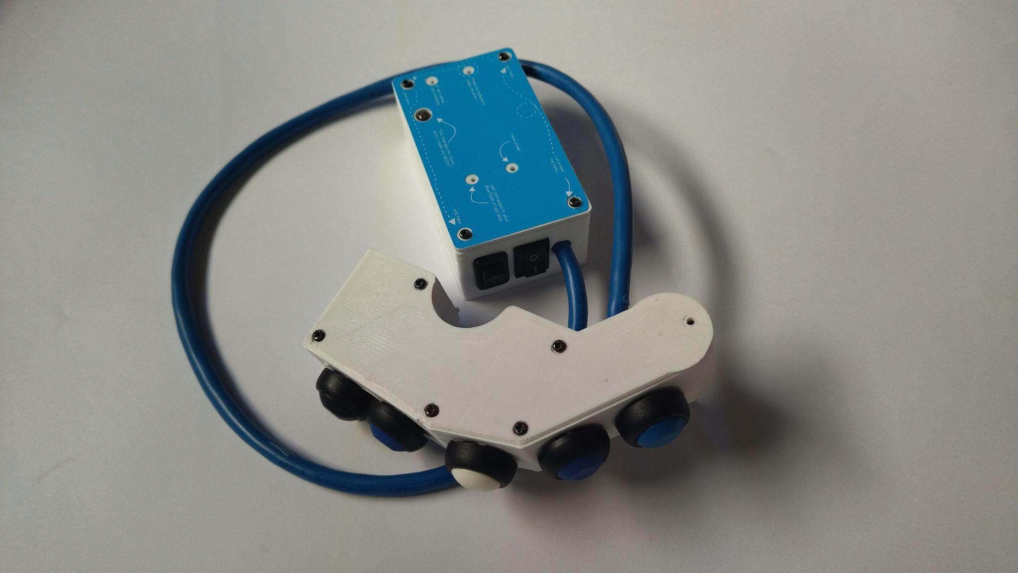
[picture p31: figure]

© Rally Rampage 2021 - www.rallyrampage.com | Page 14 of 18

## Arduino IDE Sketch 1.7 Explanation

- The 1.7 sketch is a complete new code design and changes the use of the mode rocker switch completely.
- On the new code, the one rocker switch acts as mains power from the battery.
- The other rocker switches the unit between App Use and App Select modes.
- In App Use, the buttons will have been assigned according to the softApp selected in the other mode. The unit now can have mapping of up to 5 different Android apps.
- In App Select, you can select which softApp the unit must send command to.
- The App select mode you can select an app by pressing one of the 5 controller buttons to select softApp 1-5. After clicking the button, the main LED will flicker the amount of times 1-5 to confirm selection. You can then simply switch the rocker back to App mode and that app will now be used.
© Rally Rampage 2021 - www.rallyrampage.com | Page 15 of 18

### Final testing

- Once all your buttons are active and sending commands you are ready to test on your phone.
- Turn your phone’s bluetooth on.
- Select the Rally Navigator bluetooth device that should be visible now.
- Once it pairs between the devices, you should hear what I call the ‘happy sound’ to show the device is seen as a keyboard for the phone.
- To test this pairing, select your phone's HOME button. Press the top controller button which is supposed to increase the phone's volume. If you see the phones volume goes up, it works.
- Make sure which mode your phone is on by looking at the two color LEDs. One colour will represent one mode, the other colour will represent the other mode.
- If you have used my normal sketch for your buttons, Mode 1 will have the functions for Locus Maps and the other Mode should work with media.

## Suggestions

1. You can assemble the electronics first using a non-soldering breadboard (https://www.robotics.org.za/NE00352).
a. This works great to learn and understand the workings, code and layout.
© Rally Rampage 2021 - www.rallyrampage.com | Page 16 of 18

## Final thoughts

This is an open-source project to allow other parties to contribute to the code, design and project.

If you make improvements, please forward them back to us so we can eventually launch it publicly on our website.

Thanks for your involvement.

Eugene Beetge
info@rallyrampage.com
South Africa

## GITHUB

This project is also available on GitHub at: https://github.com/eugeneworldwide/rampage_navigation_controller

© Rally Rampage 2021 - www.rallyrampage.com | Page 17 of 18

## Open Source License - Conditions

This project is offered under the GNU Affero General Public License v3.0 The content of the license text is available at: https://www.gnu.org/licenses/

© Rally Rampage 2021 - www.rallyrampage.com | Page 18 of 18

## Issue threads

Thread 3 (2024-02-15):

nut inlets too small

bororda, 2024-02-15:
internal nut holders are too small - nuts won't fit Slim/Hardware/case/Body1.stl
currently 4.5 mm
expected 5.5 mm

Closed 2024-02-15.

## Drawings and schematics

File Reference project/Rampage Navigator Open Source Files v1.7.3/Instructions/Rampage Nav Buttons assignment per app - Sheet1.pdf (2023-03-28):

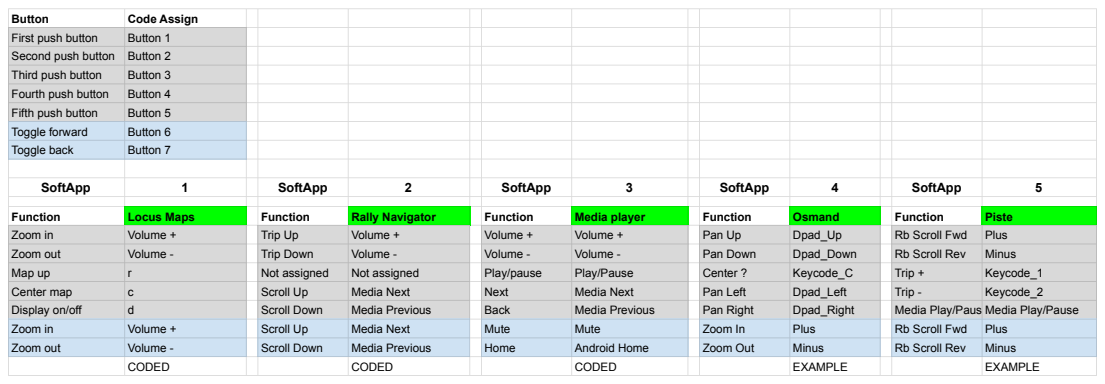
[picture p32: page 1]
Button; Code Assign; SoftApp; CODED; EXAMPLE

First push button Button 1 Second push button Button 2 Third push button Button 3 Fourth push button Button 4 Fifth push button Button 5

Toggle forward Button 6 Toggle back Button 7

Function | Locus Maps | Function | Rally Navigator | Function | Media player | Function | Osmand | Function | Piste
Zoom in Volume + Zoom out Volume -Map up r Center map c Display on/off d | | Trip Up Volume + Trip Down Volume -Not assigned Not assigned Scroll Up Media Next Scroll Down Media Previous | | Volume + Volume + Volume -Volume -Play/pause Play/Pause Next Media Next Back Media Previous | | Pan Up Dpad_Up Pan Down Dpad_Down Center ? Keycode_C Pan Left Dpad_Left Pan Right Dpad_Right | | Rb Scroll Fwd Plus Rb Scroll Rev Minus Trip + Keycode_1 Trip -Keycode_2 Media Play/PauseMedia Play/Pause

Zoom in Volume + Zoom out Volume - | | Scroll Up Media Next Scroll Down Media Previous | | Mute Mute Home Android Home | | Zoom In Plus Zoom Out Minus | | Rb Scroll Fwd Plus Rb Scroll Rev Minus

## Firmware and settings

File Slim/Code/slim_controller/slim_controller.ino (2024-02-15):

#include <BleKeyboardBeta.h>

#define led 32

//PUSH BUTTONS
#define button1 25
#define button2 23
#define button3 33

//TOGGLE SWITCH BUTTONS
#define button4 18
#define button5 19

BleKeyboard bleKeyboard;

unsigned long debounce1;
unsigned long debounce2;
int lag = 300;

bool buttonOnePressed = false;
bool buttonTwoPressed = false;
bool buttonThreePressed = false;

void setup() {
  bleKeyboard.begin();
  delay(5000);
  
  pinMode(button1, INPUT_PULLUP);
  pinMode(button2, INPUT_PULLUP);
  pinMode(button3, INPUT_PULLUP);
  pinMode(button4, INPUT_PULLUP);
  pinMode(button5, INPUT_PULLUP);
  pinMode(led, OUTPUT);

  //Attachinterrupt
  setAttaches();
}

void loop() {
  if (millis() - debounce1 > lag) {
    if (digitalRead(button4) == LOW) {
      bleKeyboard.write(KEY_MEDIA_VOLUME_UP);
    }
    if (digitalRead(button5) == LOW) {
      bleKeyboard.write(KEY_MEDIA_VOLUME_DOWN);
    }
    debounce1 = millis();
  }
  if (buttonOnePressed) {
    bleKeyboard.print("c");
    buttonOnePressed = false;
  }
  if (buttonTwoPressed) {
    bleKeyboard.write(KEY_UP_ARROW);
    buttonTwoPressed = false;
  }
  if (buttonThreePressed) {
    bleKeyboard.write(KEY_DOWN_ARROW);
    buttonThreePressed = false;
  }
}
/*
When we flag a piece of code with the IRAM_ATTR attribute, 
the compiled code is placed in the ESP32’s Internal RAM (IRAM). 
Otherwise the code is kept in Flash. And Flash on ESP32 is much slower than internal RAM.
*/
void IRAM_ATTR buttonOne() {
  if (millis() - debounce2 > lag) {
    buttonOnePressed = true;
    debounce2 = millis();
  }
}
void IRAM_ATTR buttonTwo() {
  if (millis() - debounce2 > lag) {
    buttonTwoPressed = true;
    debounce2 = millis();
  }
}
void IRAM_ATTR buttonThree() {
  if (millis() - debounce2 > lag) {
    buttonThreePressed = true;
    debounce2 = millis();
  }
}
void setAttaches() {  //has to be after the functions, otherwise fails with not declared with the IRAM_ATTR
  attachInterrupt(digitalPinToInterrupt(button1), buttonOne, FALLING);
  attachInterrupt(digitalPinToInterrupt(button2), buttonTwo, FALLING);
  attachInterrupt(digitalPinToInterrupt(button3), buttonThree, FALLING);
}

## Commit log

2024-01-27 refactored 3d model towards slimness
    [AKP_Body1.stl, AKP_Body2.stl, AKP_Body3.stl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]
2024-01-29 fixed 3d model for slim
    [AKP_Body1.stl, AKP_Body2.stl, AKP_Body3.stl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]
2024-02-15 slim photos
    [Body1.stl, Body11.stl, Body7.stl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]
2024-02-15 fixed issue #3
    [Body1.stl, parts.xlsx]
